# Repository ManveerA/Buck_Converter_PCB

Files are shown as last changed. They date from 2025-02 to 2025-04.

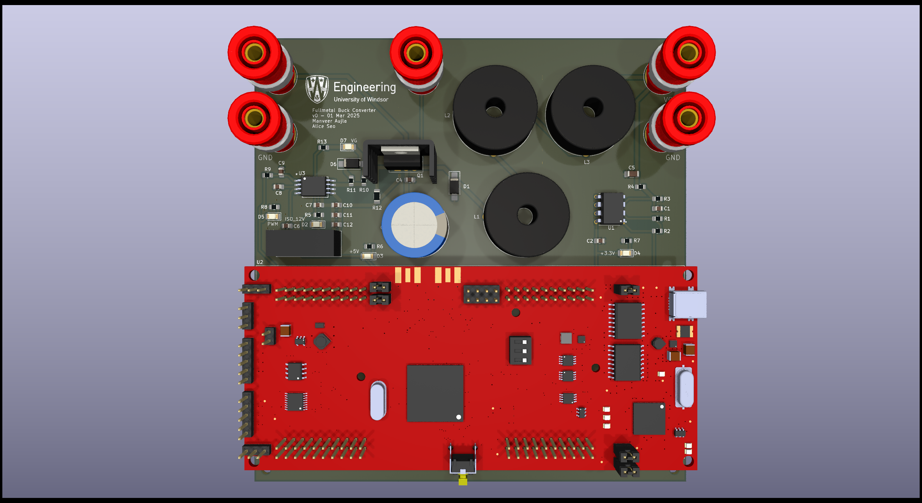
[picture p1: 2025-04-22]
3D_View.png

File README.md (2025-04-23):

Repository for Buck Converter PCB design project for ELEC-4450 Power Electronics.

See ELEC-4500 - Project Report.pdf for pictures of the board and see ELEC-4500 - Preliminary Design.pdf for the simulations and initial design.

Author: Manveer Aujla

Contact: aujla21@uwindsor.ca (school) | manveeraujla0226@gmail.com (personal) 

Last updated: 2025-04-23

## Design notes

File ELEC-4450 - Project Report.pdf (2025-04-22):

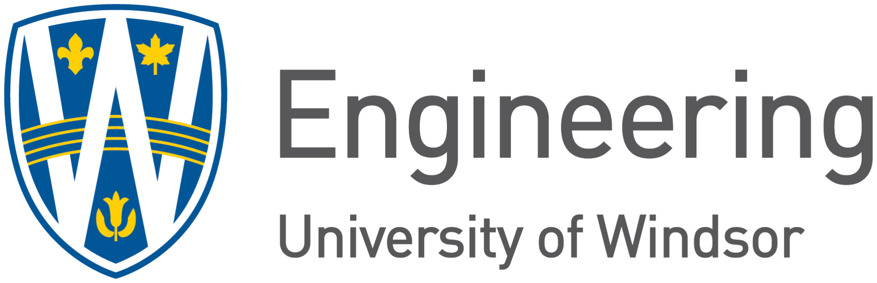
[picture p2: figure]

ELEC-4450: Power Electronics

Instructor: Dr. Caniggia Viana

## Switched-Mode Power Supply: Project Report

Manveer Aujla | 110072428
Alice Seo | 110072503

17 April 2025

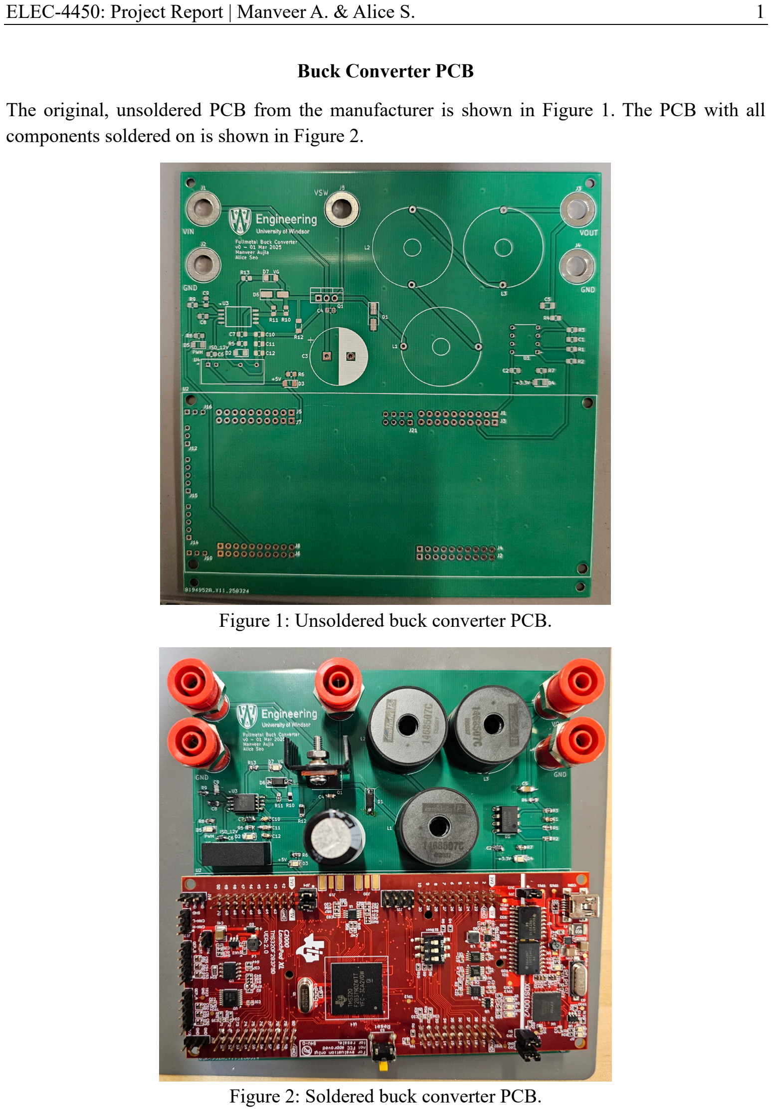
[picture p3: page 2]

ELEC-4450: Project Report | Manveer A. & Alice S. | 1

Buck Converter PCB
The original, unsoldered PCB from the manufacturer is shown in Figure 1. The PCB with all components soldered on is shown in Figure 2.

Figure 1: Unsoldered buck converter PCB.

Figure 2: Soldered buck converter PCB.

The converter connected to a laptop and the Festo machine, showing the appropriate LEDs lit, is shown in Figure 3.

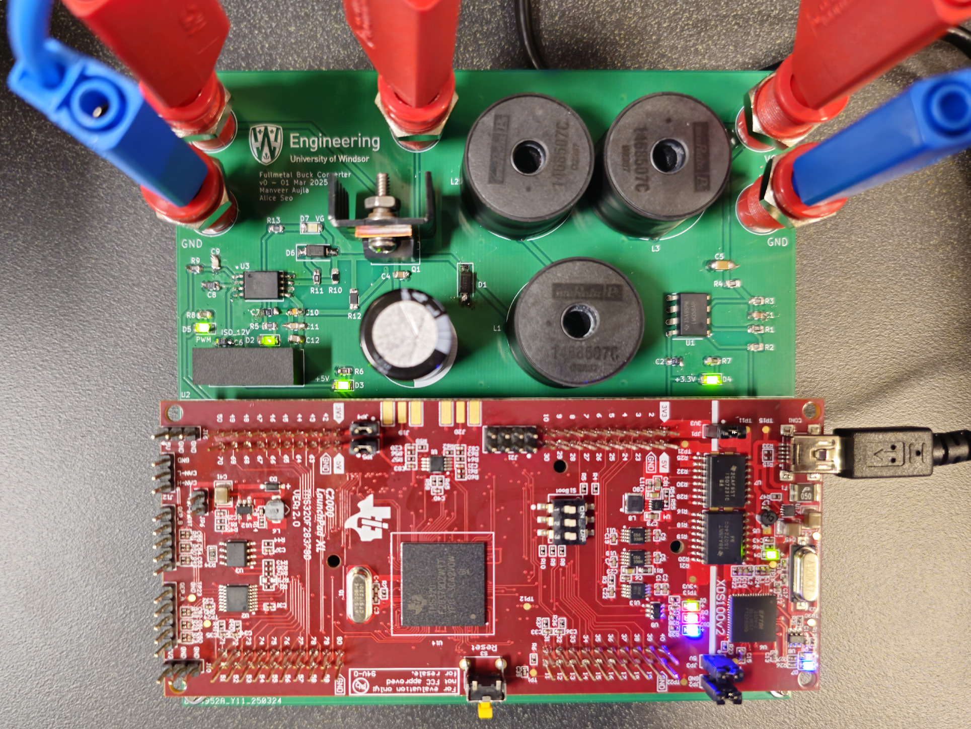
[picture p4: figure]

Figure 3: Converter connected to the laptop and Festo machine.

Design Changes
Since the Preliminary Design, only a few changes were made to the PCB design:
- Trace widths were increased to a minimum of 0.5 mm
- Surface-mounted LM358 op amp was replaced with a through-hole variant
- Mounting holes were added to the PCB layout
- GA-recommended MCU headers and standoffs were added to the BOM
Changes to the buck converter PCB that were made when debugging and testing are discussed thoroughly in the subsequent sections.

PCB Bring Up: Assembly
In the Preliminary Design, we formulated a PCB bring-up plan. This section describes the assembly and soldering process.
Out-of-Box Visual Inspection
All components ordered from Digikey were accounted for and the PCB from JLCPCB had no visual issues.
Build & Solder the Board
We have relatively little soldering experience, so soldering all of the components onto the board, particularly the surface-mounted gate driver IC, was a challenging but rewarding learning experience. We made some mistakes, such as soldering the Schottky diode in the wrong direction. However, we were able to remedy all mistakes without issue. With each component we soldered onto the board, we used a multimeter to check the continuity between adjacent components/pads to ensure that it matched the layout on KiCad.
Post-Solder Inspection
We made sure that all components were secured to the board as expected, mechanically and electrically. Using a multimeter, we performed a final sanity check on the board to ensure all connections were as expected.

PCB Bring Up: Testing & Debugging This section describes the testing and debugging process of our PCB.
IC Power and Sanity Test

The MCU was supplied with VVCC = 5 V from the Micro-USB connection to a laptop. We noted

that the +5V and +3.3V LEDs were on as expected. The ISO_12 LED, although on, was dimmer than the other LEDs. We had chosen resistors in series with each LED to provide roughly 10 mA of current for each specific voltage; since the LED was dim, it meant the output voltage from the isolated power supply was less than expected. The isolated power supply should take a 5 V input from the MCU and boost it to 12 V references to its isolated ground so that the gate driver can route it to bias the high-side switched MOSFET. We measured the output of the isolated power supply VVISO12 = 3.5 V (measuring ISO_12 with respect to ISO_GND). Apparently, the isolated

power supply was not doing its job.

We measured the resistance between ISO_12 to ISO_GND to be about RRISO-out = 3 kΩ, meaning

there was not a massive load (e.g., a DC short) demanding tons of current at the output side of the power supply. After investigation, our theory was that the isolated power supply IC must be defective. To fix this, we borrowed an IC from another group and desoldered the old, seemingly dysfunctional, IC. However, after desoldering the 4-pin IC (using three pairs of hands), solder remained on the through holes. It was too difficult to solder on the new IC because we would need to heat each pin simultaneously and push it into the PCB. So, we engineered a solution: using some jumper wires, electrical tape, and alligator clips, we attached the new isolated power supply to the board. To our dismay, repeating the IC power test showed ISO_12 was still measuring about 3.5
V. Thus, our hypothesis about the IC being broken was likely incorrect.
Next, we removed the isolated power supply from the PCB and applied an external 9-V battery at the ISO_12 and ISO_GND terminals of the PCB. To our surprise, this still did not work, and the voltage somehow became limited to 3.5 V or so. Naively, we put another battery in series and tried again—causing the board to smoke. We measured RRISO-out = 20 Ω which indicated that one of the VVDD capacitors had burned. Checking our BOM, the tantalum capacitor C10 has a voltage rating of 16 V. After removing C10, we checked the resistance RRISO-out once more and it returned to 3 kΩ.

Therefore, we correctly identified that C10 was burned and consequently internally shorted. With C10 removed, the isolated power supply now outputted 12 V. We later learned from the datasheet that C10 has a polarity, and our theory is that we had connected C10 with the wrong polarity which caused the isolated power supply to be unable to provide 12 V.
Full Power Test
The MCU was programmed using Simulink via the C2000 Microcontroller Blockset (https://www.mathworks.com/products/ti-c2000-microcontroller.html) using the Formula SAE MATLAB license. The Simulink model to program the firmware is shown in Figure
4. The PID block contains the controller CC(ss) made in the Preliminary Design.

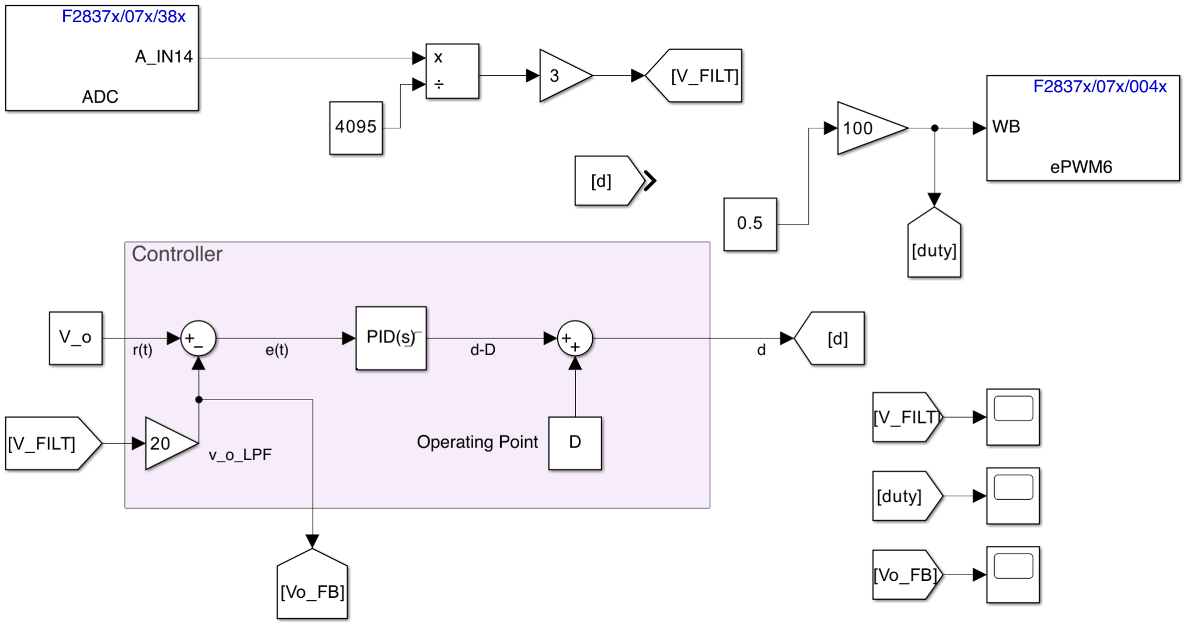
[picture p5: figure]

Figure 4: Simulink model using C2000 Microcontroller Blockset to build firmware. The test setup using the Festo machines is shown in Figure 5.

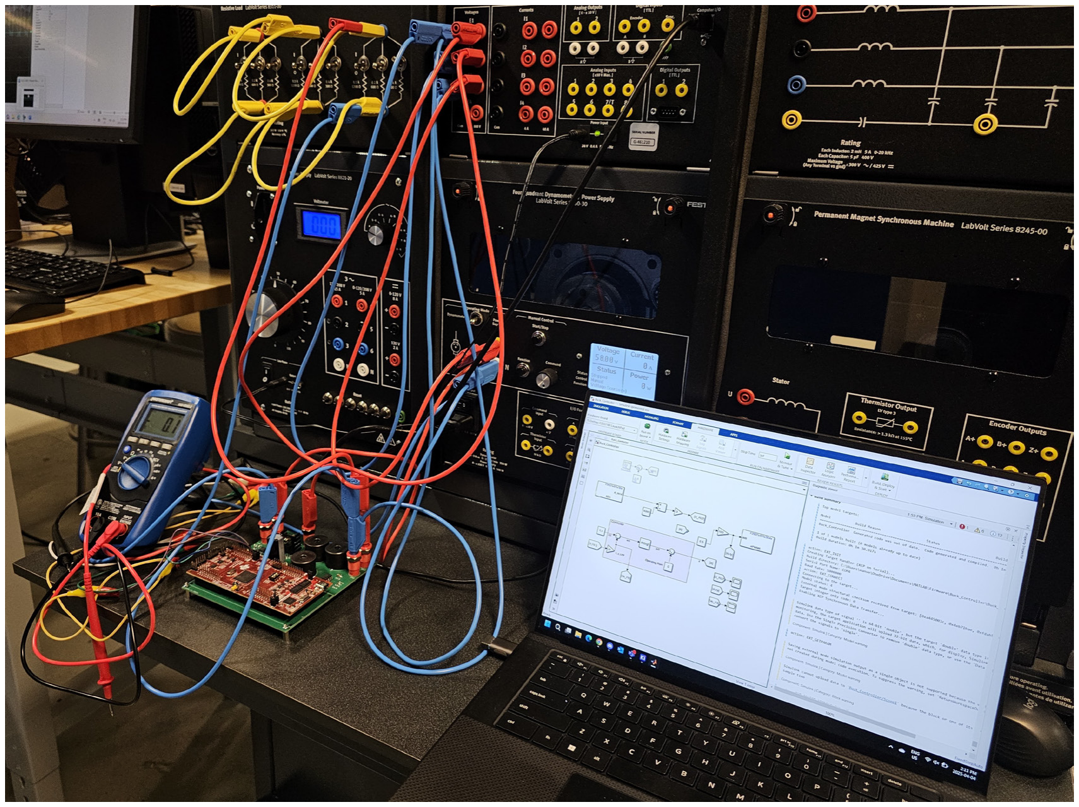
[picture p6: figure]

Figure 5: Test setup.

An input voltage of VVii = 10 V was applied to VIN from the Festo machine to the converter. The MCU was programmed for a voltage reference of VVoo

∗ = 5 V. Therefore, we would expect the duty cycle dd(tt) would adjust according to the controller such that the output voltage VVoo tracks the

reference. Unfortunately, this did not work; when the input voltage was switched on, the output voltage rose to nearly the input voltage before rapidly decaying to about 0–0.4 V and the duty cycle converged to a value of about 3.5%.
To debug, we needed to figure out whether this was a hardware or software problem. The MCU was programmed to manually set the duty cycle to 50%. In this attempt, with the input voltage of 10 V, the average output voltage went to 4.46 V, which roughly follows the conversion ratio for a buck converter. These results are shown in the next section. We then probed the hardware to compare to the ADC measurements and found that the ADC was measuring the correct voltage.

However, we noted that the LPF was not behaving as expected. Specifically, we noted that the VV+ and VV− terminals of the op amp measured a voltage difference of about 2 V or so. For an ideal op amp, VV+ = VV− and so we would expect this voltage difference to be nearly zero!

Our current hypothesis is the LPF stage hardware is compromised such that the ADC is getting a voltage reading larger than the actual normalized output voltage. In other words, since the ADC voltage determines the next iteration’s duty cycle, dd(tt) converging to 3.5% (when we expect it

should be at least greater than 50%) indicates that the controller is receiving information that we are at the reference voltage when dd(tt) = 3.5%, despite this being false. Problems notwithstanding,

we are happy that our PCB was able to, at the very least, operate as a buck converter for a given duty cycle. For true controlled buck operation, we will investigate and fix the LPF stage to achieve reference tracking for load transients.

Experimental Results
As mentioned in the previous section, our buck converter could only operate for a given duty cycle hardcoded in the firmware. That is, we were unable to use feedback control and track a reference due to hardware issues with the LPF stage. Waveforms for VVii = 5 V and dd(tt) = 100% are shown

in Figure 6.

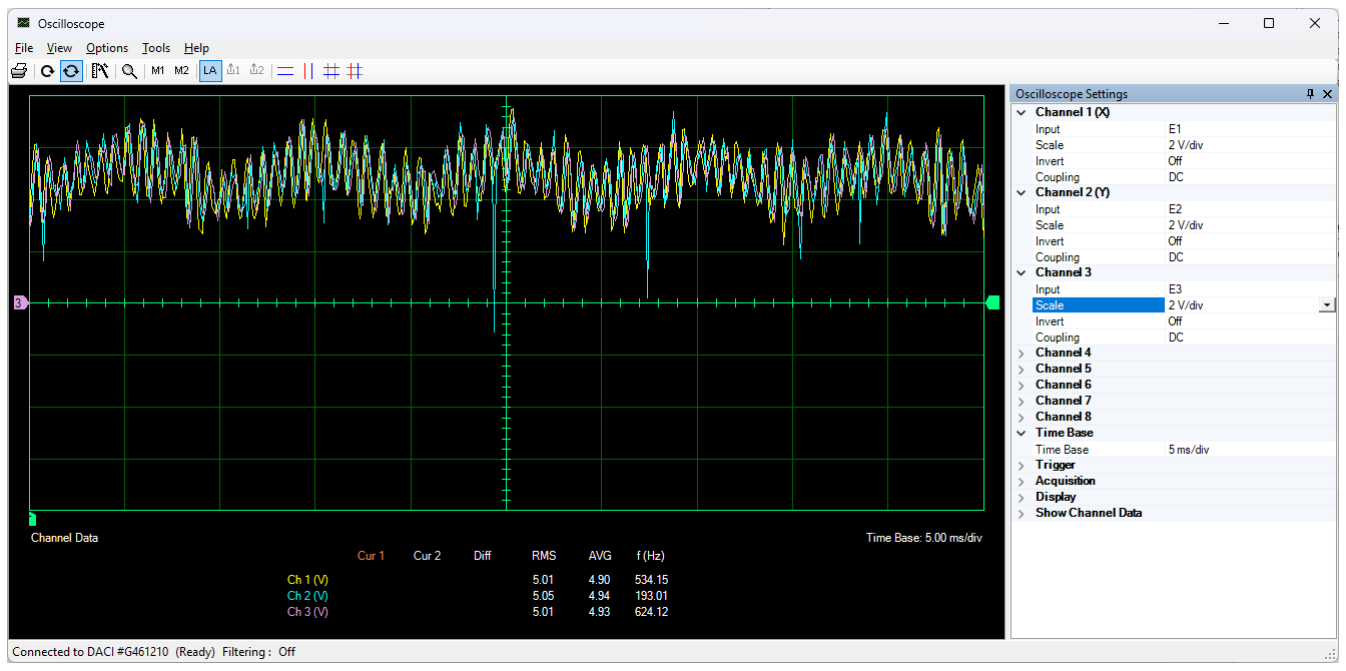
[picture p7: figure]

Figure 6: Waveforms of VVoo (Ch1), VVsw (Ch2), and VVii (Ch3) for VVii = 5 V and dd(tt) = 100%.

The input voltage essentially passes to the output, as expected with a duty cycle of 100%. That is,

VVii ≈ (100%)VVoo. Waveforms for VVii = 10 V and dd(tt) = 50% are shown in Figure 7.

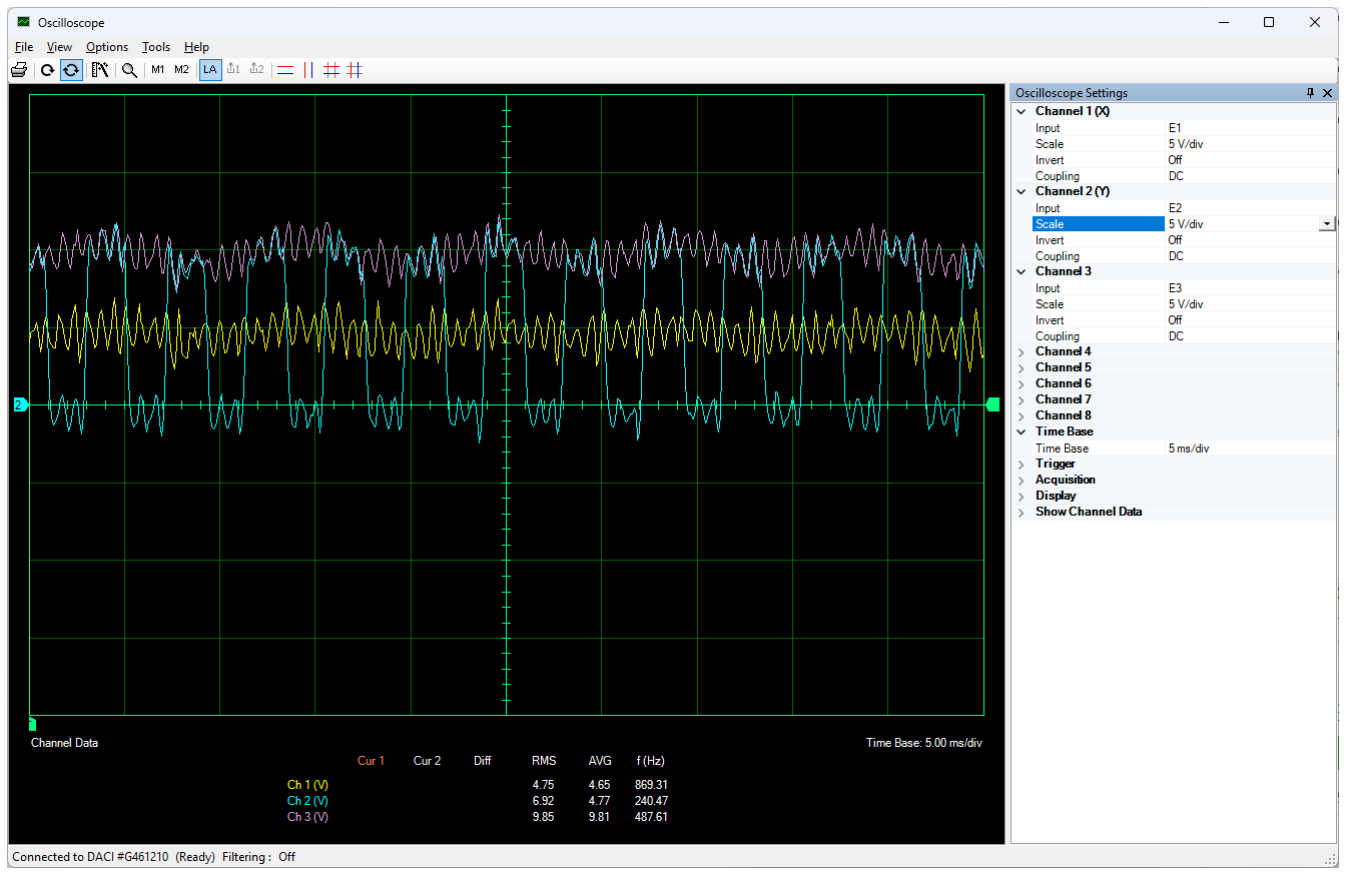
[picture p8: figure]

Figure 7: Waveforms of VVoo (Ch1), VVsw (Ch2), and VVii (Ch3) for VVii = 10 V and dd(tt) = 50%. For a duty cycle of 50%, an ideal buck would output VVoo = 50%VVii = 5 V. However, we have losses

that are unaccounted for; this is the purpose of the controller with feedback. Despite us not designing for the losses, the controller with feedback allows us to track references despite not using a robust model for the plant (i.e., the buck converter). Since we did not achieve feedback control, the best we could do was manually set a duty cycle. We can see that the buck converter is behaving as expected for its conversion ratio.

Individual Contribution
Manveer Aujla
My main contributions to the project include designing the PCB, designing and simulating the controller, selecting components based on the design constraints and making the BOM, soldering PCB components, debugging and reworking the PCB to make it functional as a buck converter, programming the firmware on the MCU, writing the bulk of the Preliminary Design, writing the ethical implications essay, and writing the final report.

Alice Seo
My contribution to the project includes checking over the PCB layout, components, and BOM, measuring the spacings between the components, soldering some PCB components and continuity testing, and contributing to writing the Preliminary Design and the ethical implications essay.

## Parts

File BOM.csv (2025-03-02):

Part Number | Reference | Value | Qty | Description | Datasheet | Footprint
CGA4J3X7R1H155K125AB | C1 | 1.5u | 1 | 1.5 ÂµF Â±10% 50V Ceramic Capacitor X7R 0805 (2012 Metric) | https://product.tdk.com/system/files/dam/doc/product/capacitor/ceramic/mlcc/catalog/mlcc_automotive_general_en.pdf | Capacitor_SMD:C_0805_2012Metric_Pad1.18x1.45mm_HandSolder
TMCP1D105MTRF | C2,C6,C7,C8 | 1u | 4 | 1 ÂµF Molded Tantalum Capacitors 20 V 0805 (2012 Metric) 11Ohm @ 100kHz | https://www.vishay.com/docs/40179/tmcp.pdf | Capacitor_SMD:C_0805_2012Metric_Pad1.18x1.45mm_HandSolder
100ZLH470MEFC16X31.5 | C3 | 470u | 1 | 470 ÂµF 100 V Aluminum Electrolytic Capacitors Radial, Can 10000 Hrs @ 105Â°C | https://www.rubycon.co.jp/wp-content/uploads/catalog-aluminum/ZLH.pdf | Capacitor_THT:CP_Radial_D18.0mm_P7.50mm
GRM21BC72A105KE01L | C4 | 1u | 1 | 1 ÂµF Â±10% 100V Ceramic Capacitor X7S 0805 (2012 Metric) | https://search.murata.co.jp/Ceramy/image/img/A01X/G101/ENG/GRM21BC72A105KE01-01.pdf | Capacitor_SMD:C_0805_2012Metric_Pad1.18x1.45mm_HandSolder
GRM31CC72A475KE11L | C5 | 4.7u | 1 | 4.7 ÂµF Â±10% 100V Ceramic Capacitor X7S 1206 (3216 Metric) | https://search.murata.co.jp/Ceramy/image/img/A01X/G101/ENG/GRM31CC72A475KE11-01A.pdf | Capacitor_SMD:C_1206_3216Metric_Pad1.33x1.80mm_HandSolder
C0805C330K5GACTU | C9 | 33p | 1 | 33 pF Â±10% 50V Ceramic Capacitor C0G, NP0 0805 (2012 Metric) | https://search.kemet.com/download/datasheet/C0805C330K5GAC7800 | Capacitor_SMD:C_0805_2012Metric_Pad1.18x1.45mm_HandSolder
F951C106MPAAQ2 | C10 | 10u | 1 | 10 ÂµF Conformal Coated Tantalum Capacitors 16 V 0805 (2012 Metric) 4Ohm | https://datasheets.kyocera-avx.com/F95.pdf | Capacitor_SMD:C_0805_2012Metric_Pad1.18x1.45mm_HandSolder
C0805C224K5RACTU | C11 | 220n | 1 | 0.22 ÂµF Â±10% 50V Ceramic Capacitor X7R 0805 (2012 Metric) | https://search.kemet.com/download/datasheet/C0805C224K5RAC7800 | Capacitor_SMD:C_0805_2012Metric_Pad1.18x1.45mm_HandSolder
GRM21BR61E106KA73L | C12 | 10u | 1 | 10 ÂµF Â±10% 25V Ceramic Capacitor X5R 0805 (2012 Metric) | https://search.murata.co.jp/Ceramy/image/img/A01X/G101/ENG/GRM21BR61E106KA73-01.pdf | Capacitor_SMD:C_0805_2012Metric_Pad1.18x1.45mm_HandSolder
SS310 | D1 | ---- | 1 | Diode 100 V 3A Surface Mount DO-214AC (SMA) | https://services.taiwansemi.com/storage/resources/datasheet/SS32%20SERIES_Q2412.pdf | Diode_SMD:D_SMA_Handsoldering
LTST-C150GKT | D2,D3,D4,D5,D7 | ---- | 5 | Green 569nm LED Indication - Discrete 2.1V | https://optoelectronics.liteon.com/upload/download/DS-22-98-0004/LTST-C150GKT.pdf | LED_SMD:LED_1206_3216Metric_Pad1.42x1.75mm_HandSolder
US2AA | D6 | ---- | 1 | 50V, 1.5A, General Purpose Rectifier Diode, SMA(DO-214AC) | https://www.onsemi.com/pdf/datasheet/us2aa-d.pdf | Diode_SMD:D_SMA_Handsoldering
BU-P72930-2 | J1,J2,J3,J4,J5 | ---- | 5 | Generic connector, single row, 01x01, script generated | https://www.muellerelectric.com/product_files/986/DS-BU-P72930-@.pdf | Connector:Banana_Jack_1Pin
1468507C | L1,L2,L3 | 6.8m | 3 | FIXED IND 6.8MH 700MA 2.3 OHM TH | https://search.murata.co.jp/Ceramy/image/img/P02A/kmp_1400.pdf | Inductor_THT:L_Radial_D24.4mm_P23.10mm_Murata_1400series
IRF540NPBF | Q1 | ---- | 1 | N-Channel 100 V 33A (Tc) 130W (Tc) Through Hole TO-220AB | https://www.infineon.com/dgdl/irf540npbf.pdf?fileId=5546d462533600a4015355e39f0d19a1 | Package_TO_SOT_THT:TO-220-3_Vertical
507302B00000G | Q1 Heatsink | ---- | 1 | Heatsink for MOSFET | https://info.boydcorp.com/hubfs/Thermal/Air-Cooling/Boyd-Board-Level-Heatsinks-Catalog.pdf | ----
4880G | Q1 Heatsink Mounting Kit | ---- | 1 | Mounting kit for heatsink for MOSFET | https://info.boydcorp.com/hubfs/Thermal/Air-Cooling/Boyd-Board-Level-Heatsinks-Catalog.pdf | ----
RC0805FR-0720KL | R1,R4 | 20k | 2 | 20 kOhms Â±1% 0.125W, 1/8W Chip Resistor 0805 (2012 Metric) Moisture Resistant Thick Film | https://www.yageo.com/upload/media/product/products/datasheet/rchip/PYu-RC_Group_51_RoHS_L_12.pdf | Resistor_SMD:R_0805_2012Metric_Pad1.20x1.40mm_HandSolder
RMCF0805FT1K00 | R2,R3,R5,R13 | 1k | 4 | 1 kOhms Â±1% 0.125W, 1/8W Chip Resistor 0805 (2012 Metric) Automotive AEC-Q200 Thick Film | https://www.seielect.com/catalog/sei-rmcf_rmcp.pdf | Resistor_SMD:R_0805_2012Metric_Pad1.20x1.40mm_HandSolder
RMCF0805JT300R | R6 | 300R | 1 | 300 Ohms Â±5% 0.125W, 1/8W Chip Resistor 0805 (2012 Metric) Automotive AEC-Q200 Thick Film | https://www.seielect.com/catalog/sei-rmcf_rmcp.pdf | Resistor_SMD:R_0805_2012Metric_Pad1.20x1.40mm_HandSolder
RMCF0805FT120R | R7,R8 | 120R | 2 | 120 Ohms Â±1% 0.125W, 1/8W Chip Resistor 0805 (2012 Metric) Automotive AEC-Q200 Thick Film | https://www.seielect.com/catalog/sei-rmcf_rmcp.pdf | Resistor_SMD:R_0805_2012Metric_Pad1.20x1.40mm_HandSolder
RC0805FR-0751RL | R9 | 51R | 1 | 51 Ohms Â±1% 0.125W, 1/8W Chip Resistor 0805 (2012 Metric) Moisture Resistant Thick Film | https://www.yageo.com/upload/media/product/products/datasheet/rchip/PYu-RC_Group_51_RoHS_L_12.pdf | Resistor_SMD:R_0805_2012Metric_Pad1.20x1.40mm_HandSolder
RCS08056R80FKEA | R10 | 6.8R | 1 | 6.8 Ohms Â±1% 0.5W, 1/2W Chip Resistor 0805 (2012 Metric) Automotive AEC-Q200, Pulse Withstanding Thick Film | https://www.vishay.com/docs/20065/rcse3.pdf | Resistor_SMD:R_0805_2012Metric_Pad1.20x1.40mm_HandSolder
ERJ-P06J120V | R11 | 12R | 1 | 12 Ohms Â±5% 0.5W, 1/2W Chip Resistor 0805 (2012 Metric) Automotive AEC-Q200, Pulse Withstanding Thick Film | https://industrial.panasonic.com/cdbs/www-data/pdf/RDO0000/AOA0000C331.pdf | Resistor_SMD:R_0805_2012Metric_Pad1.20x1.40mm_HandSolder
RCP1206W50R0GEB | R12 | 50R | 1 | 50 Ohms Â±2% 2.4W Chip Resistor 1206 (3216 Metric) Moisture Resistant Thick Film | https://www.vishay.com/docs/31098/rcp.pdf | Resistor_SMD:R_1206_3216Metric_Pad1.30x1.75mm_HandSolder
LM358AP | U1 | ---- | 1 | General Purpose Amplifier 2 Circuit 8-PDIP | https://www.ti.com/general/docs/suppproductinfo.tsp?distId=10 | LM358AP:DIP794W45P254L959H508Q8
LAUNCHXL-F28379D | U2 | ---- | 1 | MCU Launchpad | https://www.ti.com/lit/pdf/sprui77 | LAUNCHXL_F28379D:MOD_LAUNCHXL-F28379D
61202021621 | U2 Connection Header | ---- | 4 | Connector Header Through Hole 20 position 0.100" (2.54mm) | https://www.we-online.com/components/products/datasheet/61202021621.pdf | ----
971100154 | PCB Standoffs | ---- | 4 | Hex Standoff Threaded M2.5 Brass 0.394" (10.00mm) Silver | https://www.we-online.com/components/products/datasheet/971100154.pdf | ----
4707 | Standoff nuts | ---- | 4 | M2.5x0.45 Hex Nut 0.197" (5.00mm) Steel | https://www.keyelco.com/userAssets/file/M65p135.pdf | ----
UCC5304DWVR | U3 | ---- | 1 | 4A, 6A Gate Driver Capacitive Coupling 5000Vrms 1 Channel 8-SOIC | https://www.ti.com/lit/gpn/ucc5304 | UCC5304DWVR:SOIC8_DWV_TEX
TMV 0512SHI | U4 | ---- | 1 | Isolated Module DC DC Converter 1 Output 12V 84mA 4.5V - 5.5V Input | https://www.tracopower.com/products/tmv-hi.pdf | TMV_0512SHI:TMV-HI_SINGLE_TRP

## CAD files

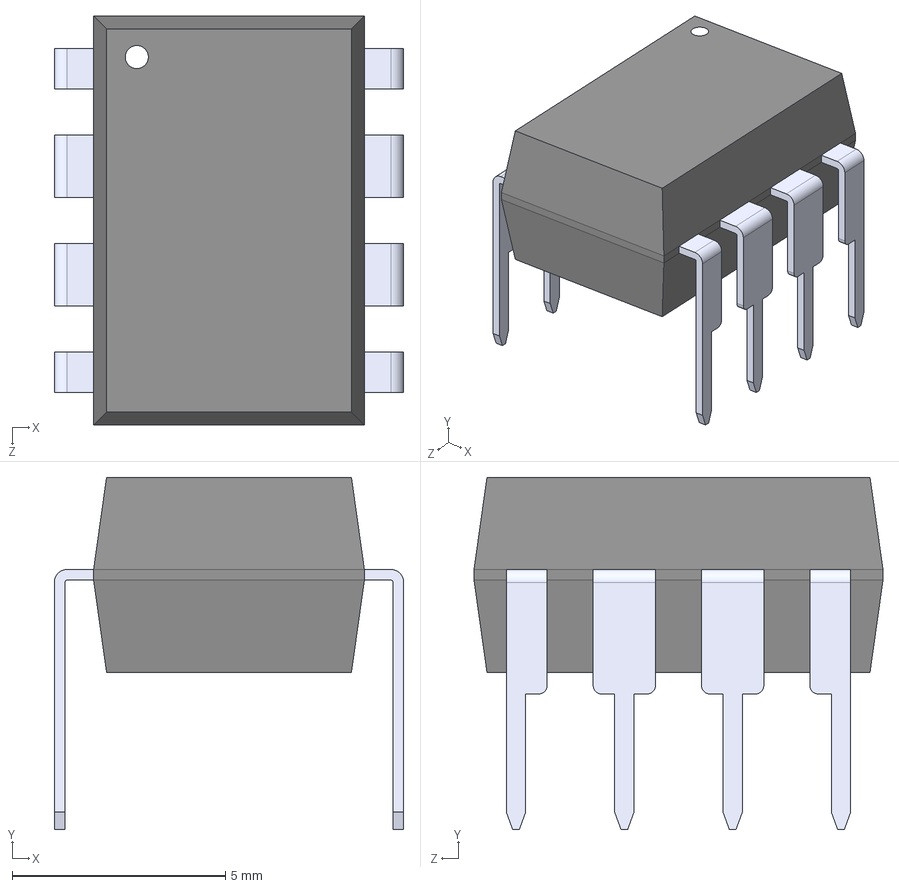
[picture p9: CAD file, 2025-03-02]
LM358AP/LM358AP.step
8.19 x 8.26 x 9.59 mm

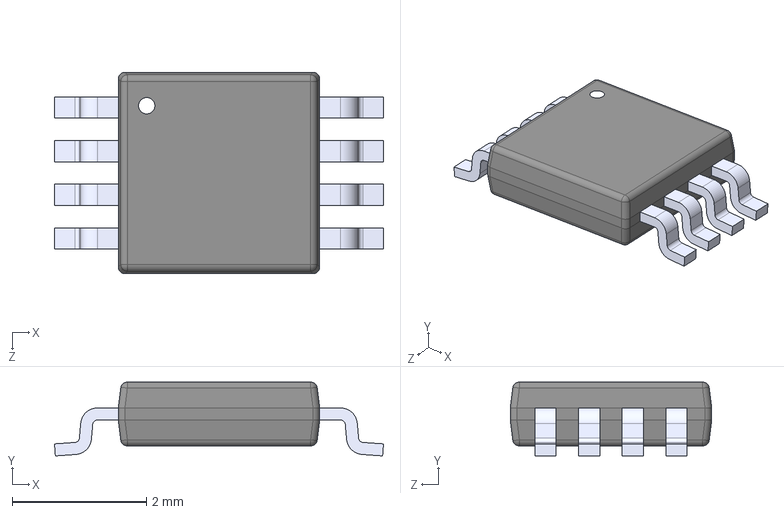
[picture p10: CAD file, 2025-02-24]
Misc/LM358DGKR.step
4.90 x 1.10 x 3.00 mm

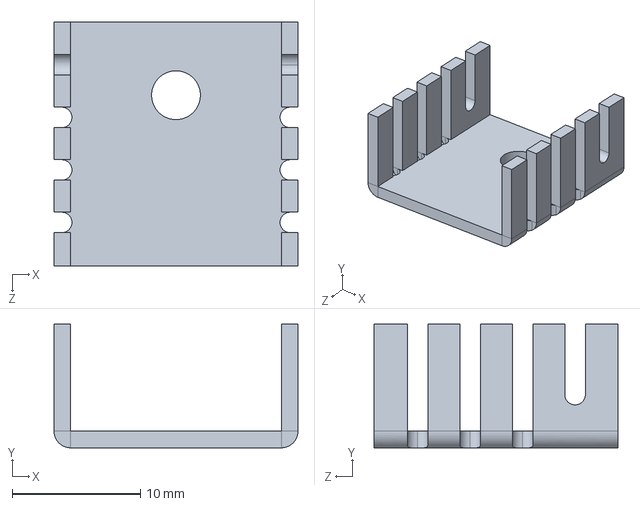
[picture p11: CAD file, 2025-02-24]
507302B00000G/507302B00000G.step
19.1 x 9.65 x 19.1 mm

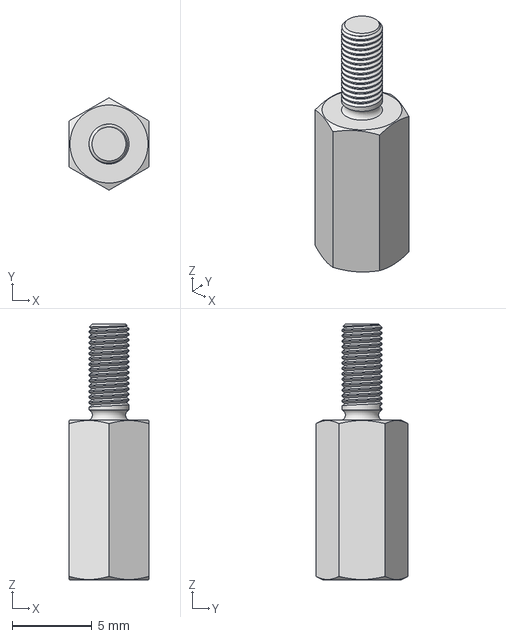
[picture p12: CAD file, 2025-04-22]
Misc/971100154.stp
5.00 x 5.77 x 16.0 mm

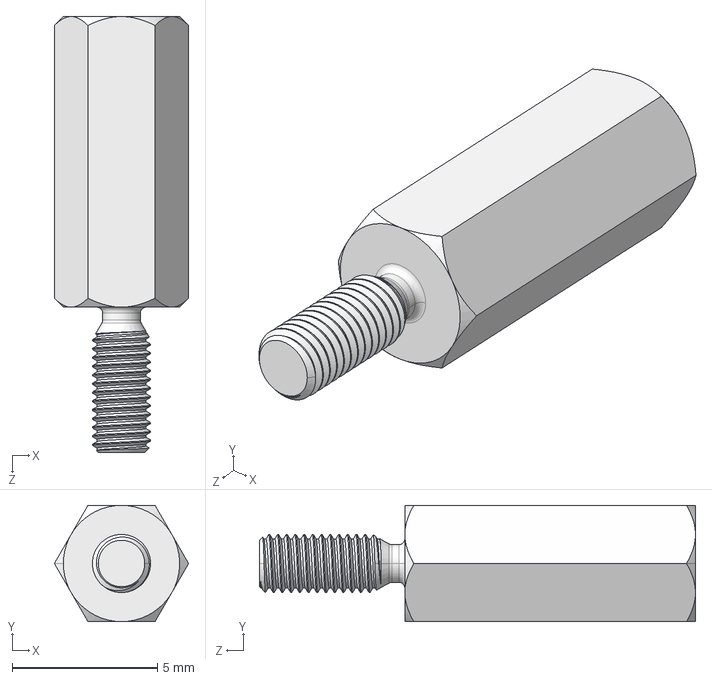
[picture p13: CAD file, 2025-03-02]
Misc/971100244.stp
4.62 x 4.00 x 15.0 mm

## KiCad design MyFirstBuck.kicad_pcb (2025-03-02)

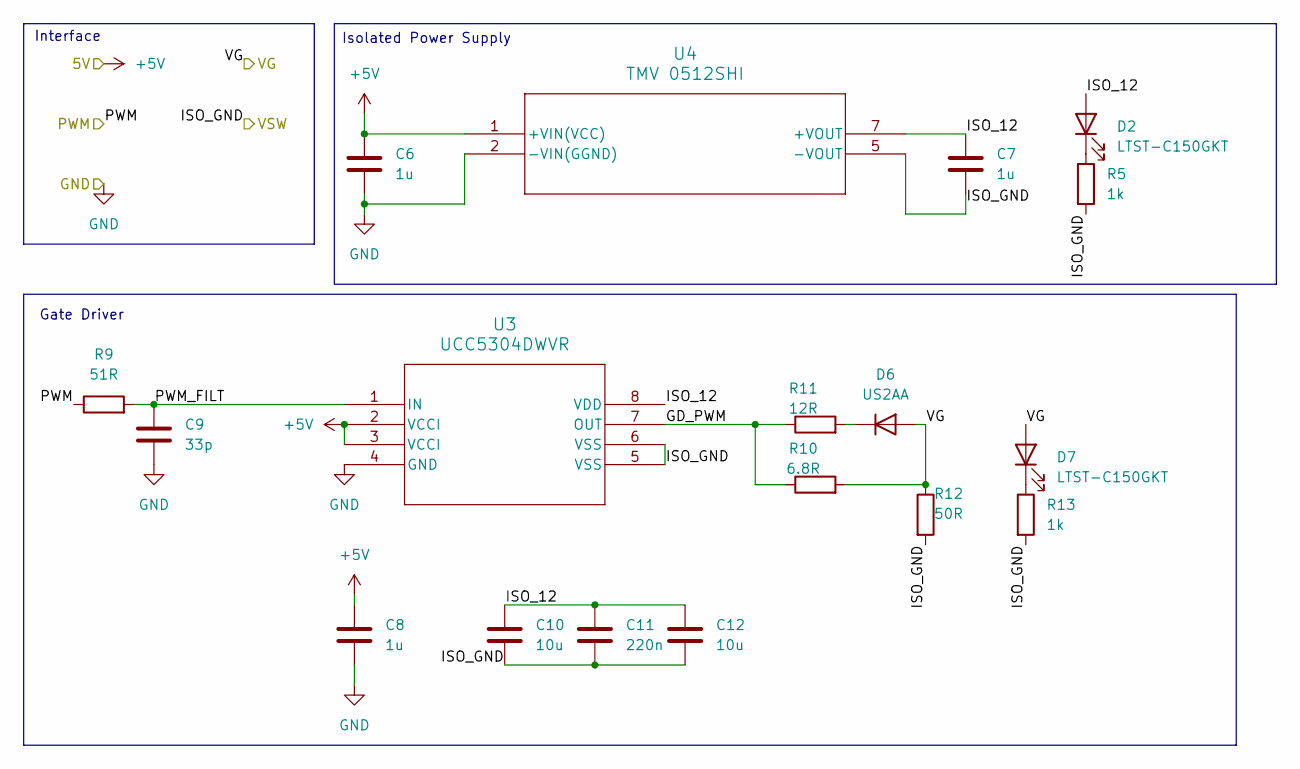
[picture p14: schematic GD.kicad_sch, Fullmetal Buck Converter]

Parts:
C6, C7, C8: 1u; C_0805_2012Metric_Pad1.18x1.45mm_HandSolder; Part Number TMCP1D105MTRF
C9: 33p; C_0805_2012Metric_Pad1.18x1.45mm_HandSolder; Part Number C0805C330K5GACTU
C10: 10u; C_0805_2012Metric_Pad1.18x1.45mm_HandSolder; Part Number F951C106MPAAQ2
C11: 220n; C_0805_2012Metric_Pad1.18x1.45mm_HandSolder; Part Number C0805C224K5RACTU
C12: 10u; C_0805_2012Metric_Pad1.18x1.45mm_HandSolder; Part Number GRM21BR61E106KA73L
D2, D7: LTST-C150GKT; LED_1206_3216Metric_Pad1.42x1.75mm_HandSolder; Part Number LTST-C150GKT
D6: US2AA; D_SMA_Handsoldering; Part Number US2AA
R5, R13: 1k; R_0805_2012Metric_Pad1.20x1.40mm_HandSolder; Part Number RMCF0805FT1K00
R9: 51R; R_0805_2012Metric_Pad1.20x1.40mm_HandSolder; Part Number RC0805FR-0751RL
R10: 6.8R; R_0805_2012Metric_Pad1.20x1.40mm_HandSolder; Part Number RCS08056R80FKEA
R11: 12R; R_0805_2012Metric_Pad1.20x1.40mm_HandSolder; Part Number ERJ-P06J120V
R12: 50R; R_1206_3216Metric_Pad1.30x1.75mm_HandSolder; Part Number RCP1206W50R0GEB
U3: UCC5304DWVR; SOIC8_DWV_TEX; Part Number UCC5304DWVR
U4: TMV 0512SHI; TMV-HI_SINGLE_TRP; Part Number TMV 0512SHI

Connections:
+5V: C6.1, C8.1, U3.2 (VCCI), U3.3 (VCCI), U4.1 (+VIN(VCC)); also elsewhere on the board
/GD/GD_PWM: R10.1, R11.1, U3.7 (OUT)
/GD/ISO_12: C7.1, C10.1, C11.1, C12.1, D2.2 (A), U3.8 (VDD), U4.7 (+VOUT)
/GD/PWM_FILT: C9.1, R9.2, U3.1 (IN)
/PWM: R9.1; also elsewhere on the board
/VG: D6.2 (A), D7.2 (A), R10.2, R12.1; also elsewhere on the board
/VSW: C7.2, C10.2, C11.2, C12.2, R5.2, R12.2, R13.2, U3.5 (VSS), U3.6 (VSS), U4.5 (-VOUT); also elsewhere on the board
GND: C6.2, C8.2, C9.2, U3.4 (GND), U4.2 (-VIN(GGND)); also elsewhere on the board
unnamed: D2.1 (K), R5.1
unnamed: D6.1 (K), R11.2
unnamed: D7.1 (K), R13.1

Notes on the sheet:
Interface
Isolated Power Supply
Gate Driver

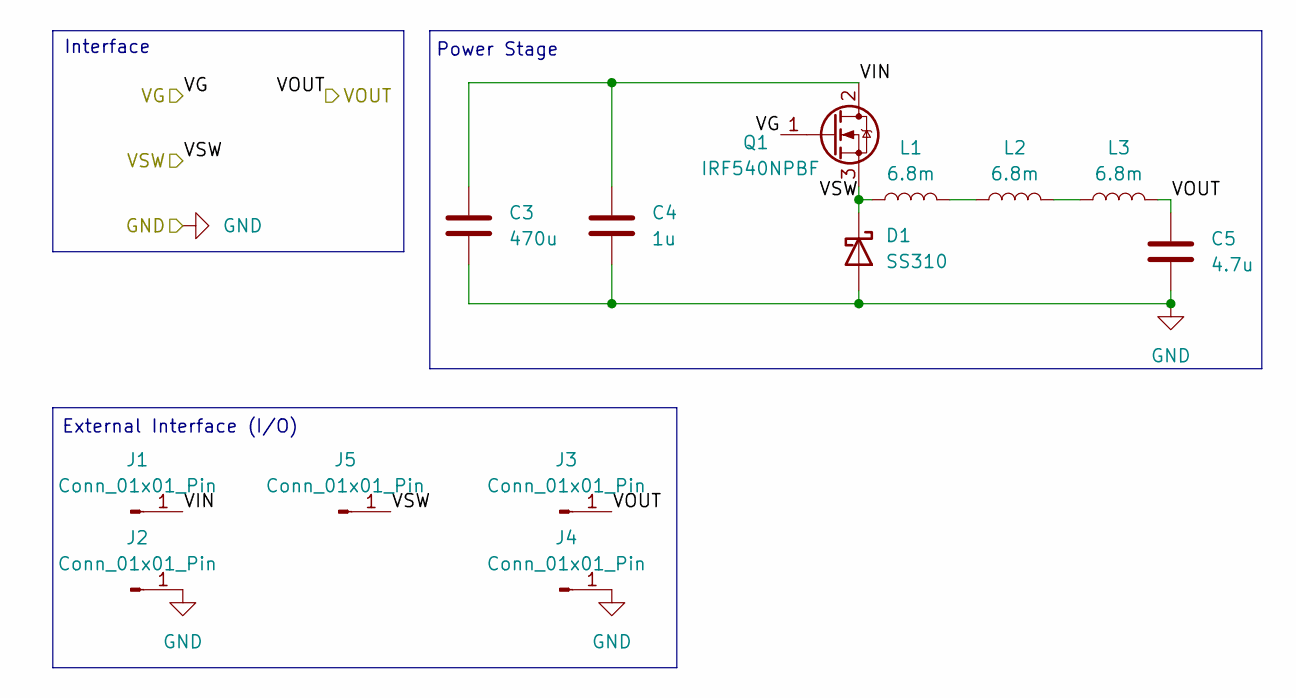
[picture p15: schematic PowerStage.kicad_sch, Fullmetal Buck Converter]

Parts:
C3: 470u; CP_Radial_D18.0mm_P7.50mm; Part Number 100ZLH470MEFC16X31.5
C4: 1u; C_0805_2012Metric_Pad1.18x1.45mm_HandSolder; Part Number GRM21BC72A105KE01L
C5: 4.7u; C_1206_3216Metric_Pad1.33x1.80mm_HandSolder; Part Number GRM31CC72A475KE11L
D1: SS310; D_SMA_Handsoldering; Part Number SS310
J1, J2, J3, J4, J5: Conn_01x01_Pin; Banana_Jack_1Pin; Part Number BU-P72930-2
L1, L2, L3: 6.8m; L_Radial_D24.4mm_P23.10mm_Murata_1400series; Part Number 1468507C
Q1: IRF540NPBF; TO-220-3_Vertical; Part Number IRF540NPBF

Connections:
/PowerStage/VIN: C3.1, C4.1, J1.1, Q1.2 (D)
/VG: Q1.1 (G); also elsewhere on the board
/VOUT: C5.1, J3.1, L3.2; also elsewhere on the board
/VSW: D1.1 (K), J5.1, L1.1, Q1.3 (S); also elsewhere on the board
GND: C3.2, C4.2, C5.2, D1.2 (A), J2.1, J4.1; also elsewhere on the board
unnamed: L1.2, L2.1
unnamed: L2.2, L3.1

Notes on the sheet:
External Interface (I/O)
Interface
Power Stage

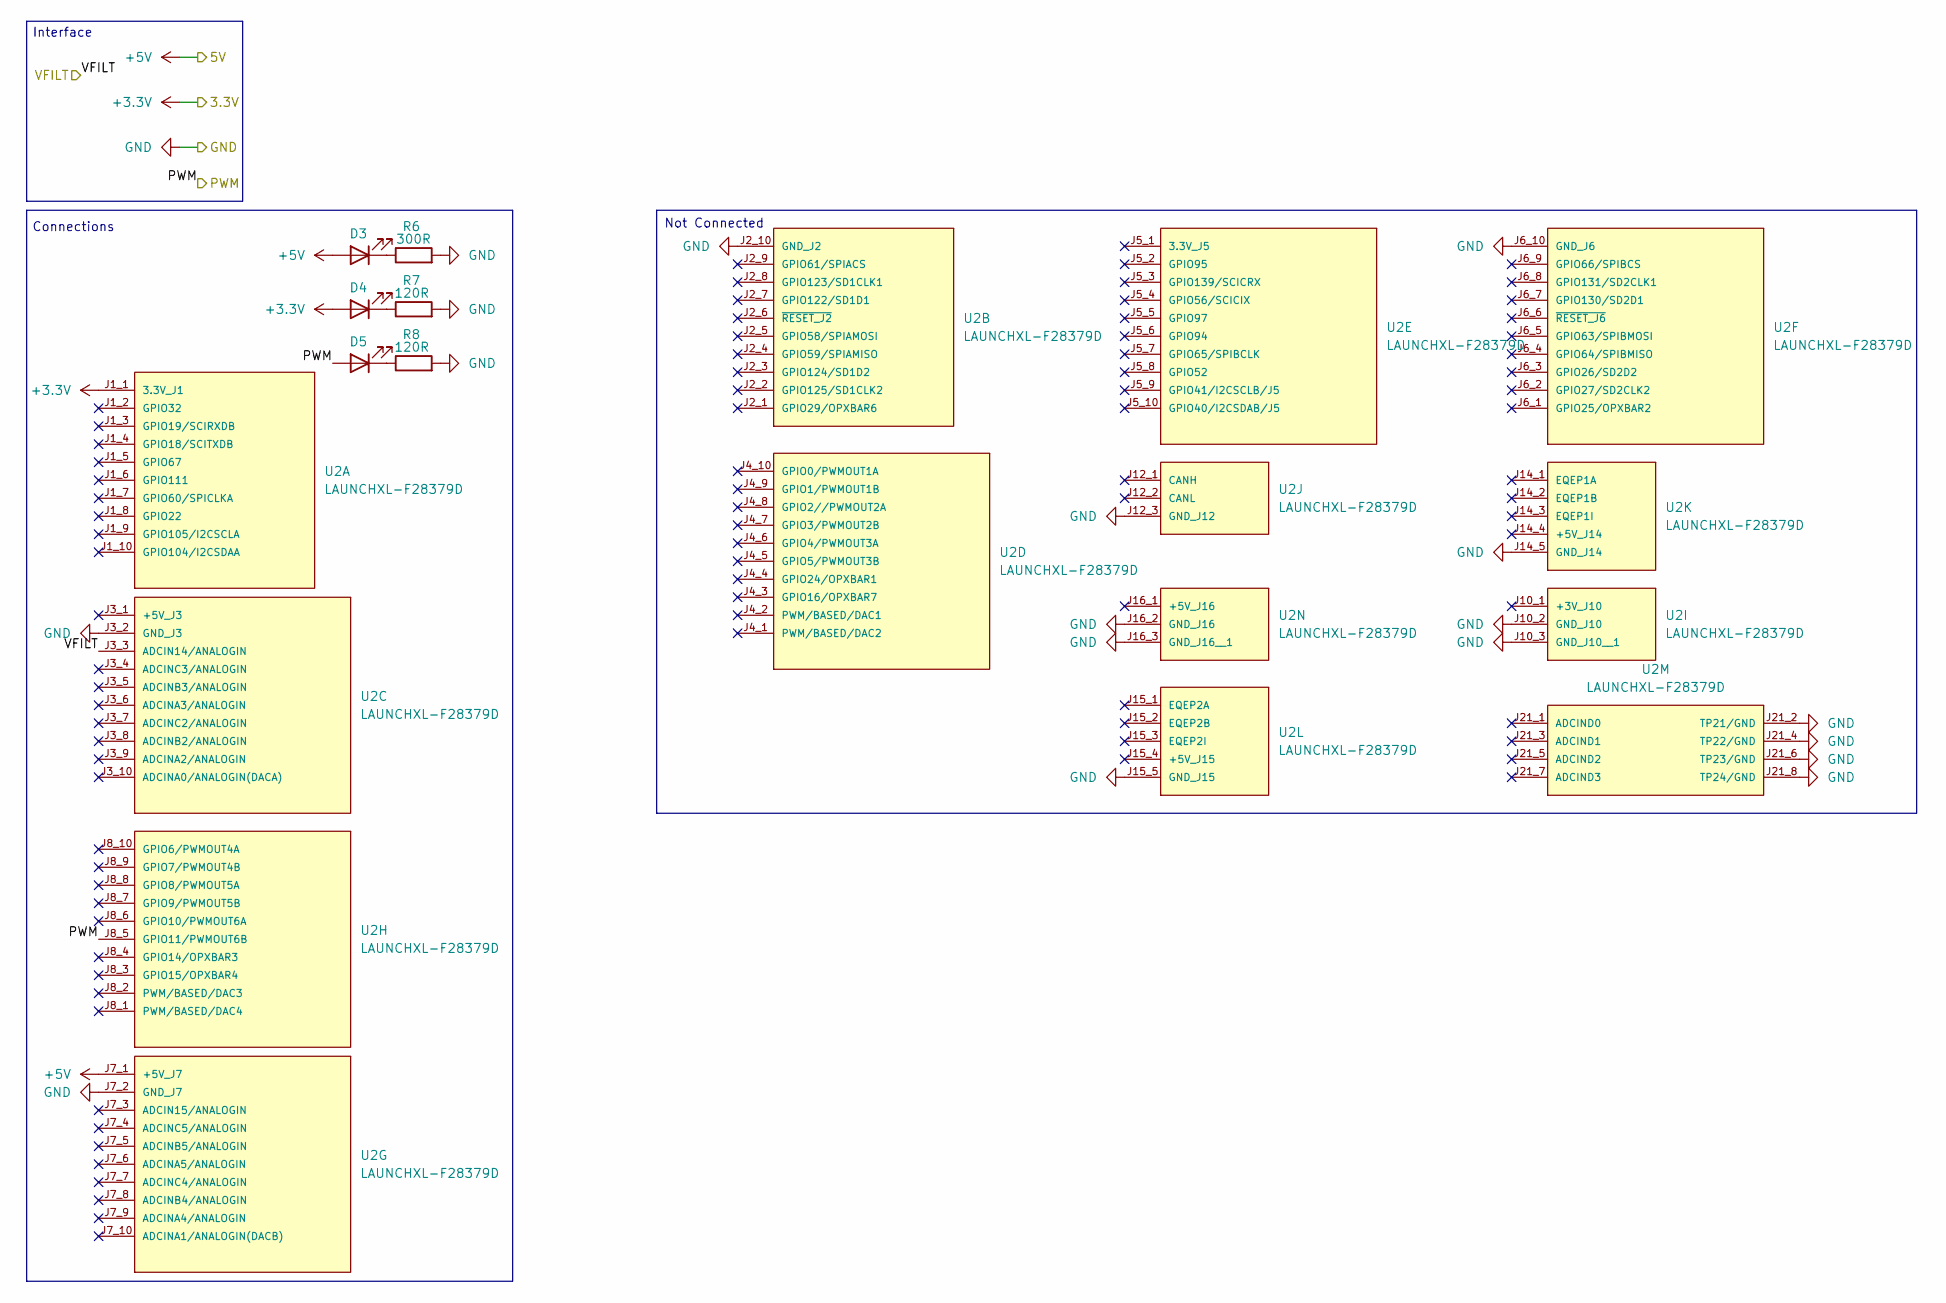
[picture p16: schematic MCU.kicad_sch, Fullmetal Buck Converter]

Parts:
D3, D4, D5: LTST-C150GKT; LED_1206_3216Metric_Pad1.42x1.75mm_HandSolder; Part Number LTST-C150GKT
R6: 300R; R_0805_2012Metric_Pad1.20x1.40mm_HandSolder; Part Number RMCF0805JT300R
R7, R8: 120R; R_0805_2012Metric_Pad1.20x1.40mm_HandSolder; Part Number RMCF0805FT120R
U2: LAUNCHXL-F28379D; MOD_LAUNCHXL-F28379D; PARTREV 2.0

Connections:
+3.3V: D4.2 (A), U2.J1_1 (3.3V_J1); also elsewhere on the board
+5V: D3.2 (A), U2.J7_1 (+5V_J7); also elsewhere on the board
/PWM: D5.2 (A), U2.J8_5 (GPIO11/PWMOUT6B); also elsewhere on the board
/VFILT: U2.J3_3 (ADCIN14/ANALOGIN); also elsewhere on the board
GND: R6.2, R7.2, R8.2, U2.J2_10 (GND_J2), U2.J3_2 (GND_J3), U2.J6_10 (GND_J6), U2.J7_2 (GND_J7), U2.J10_2 (GND_J10), U2.J10_3 (GND_J10__1), U2.J12_3 (GND_J12), U2.J14_5 (GND_J14), U2.J15_5 (GND_J15), U2.J16_2 (GND_J16), U2.J16_3 (GND_J16__1), U2.J21_2 (TP21/GND), U2.J21_4 (TP22/GND), U2.J21_6 (TP23/GND), U2.J21_8 (TP24/GND); also elsewhere on the board
unnamed: D3.1 (K), R6.1
unnamed: D4.1 (K), R7.1
unnamed: D5.1 (K), R8.1

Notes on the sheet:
Interface
Not Connected
Connections

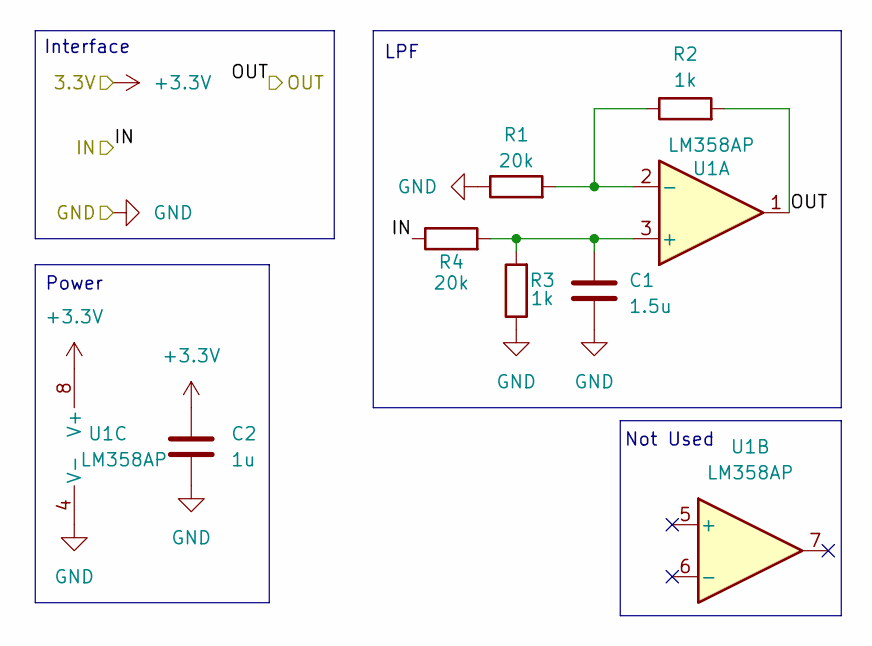
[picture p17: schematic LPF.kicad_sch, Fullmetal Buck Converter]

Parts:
C1: 1.5u; C_0805_2012Metric_Pad1.18x1.45mm_HandSolder; Part Number CGA4J3X7R1H155K125AB
C2: 1u; C_0805_2012Metric_Pad1.18x1.45mm_HandSolder; Part Number TMCP1D105MTRF
R1, R4: 20k; R_0805_2012Metric_Pad1.20x1.40mm_HandSolder; Part Number RC0805FR-0720KL
R2, R3: 1k; R_0805_2012Metric_Pad1.20x1.40mm_HandSolder; Part Number RMCF0805FT1K00
U1: LM358AP; DIP794W45P254L959H508Q8; Part Number LM358AP

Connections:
+3.3V: C2.1, U1.8 (V+); also elsewhere on the board
/VFILT: R2.2, U1.1; also elsewhere on the board
/VOUT: R4.1; also elsewhere on the board
GND: C1.2, C2.2, R1.1, R3.1, U1.4 (V-); also elsewhere on the board
unnamed: C1.1, R3.2, R4.2, U1.3 (+)
unnamed: R1.2, R2.1, U1.2 (-)

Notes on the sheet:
Power
Interface
Not Used
LPF

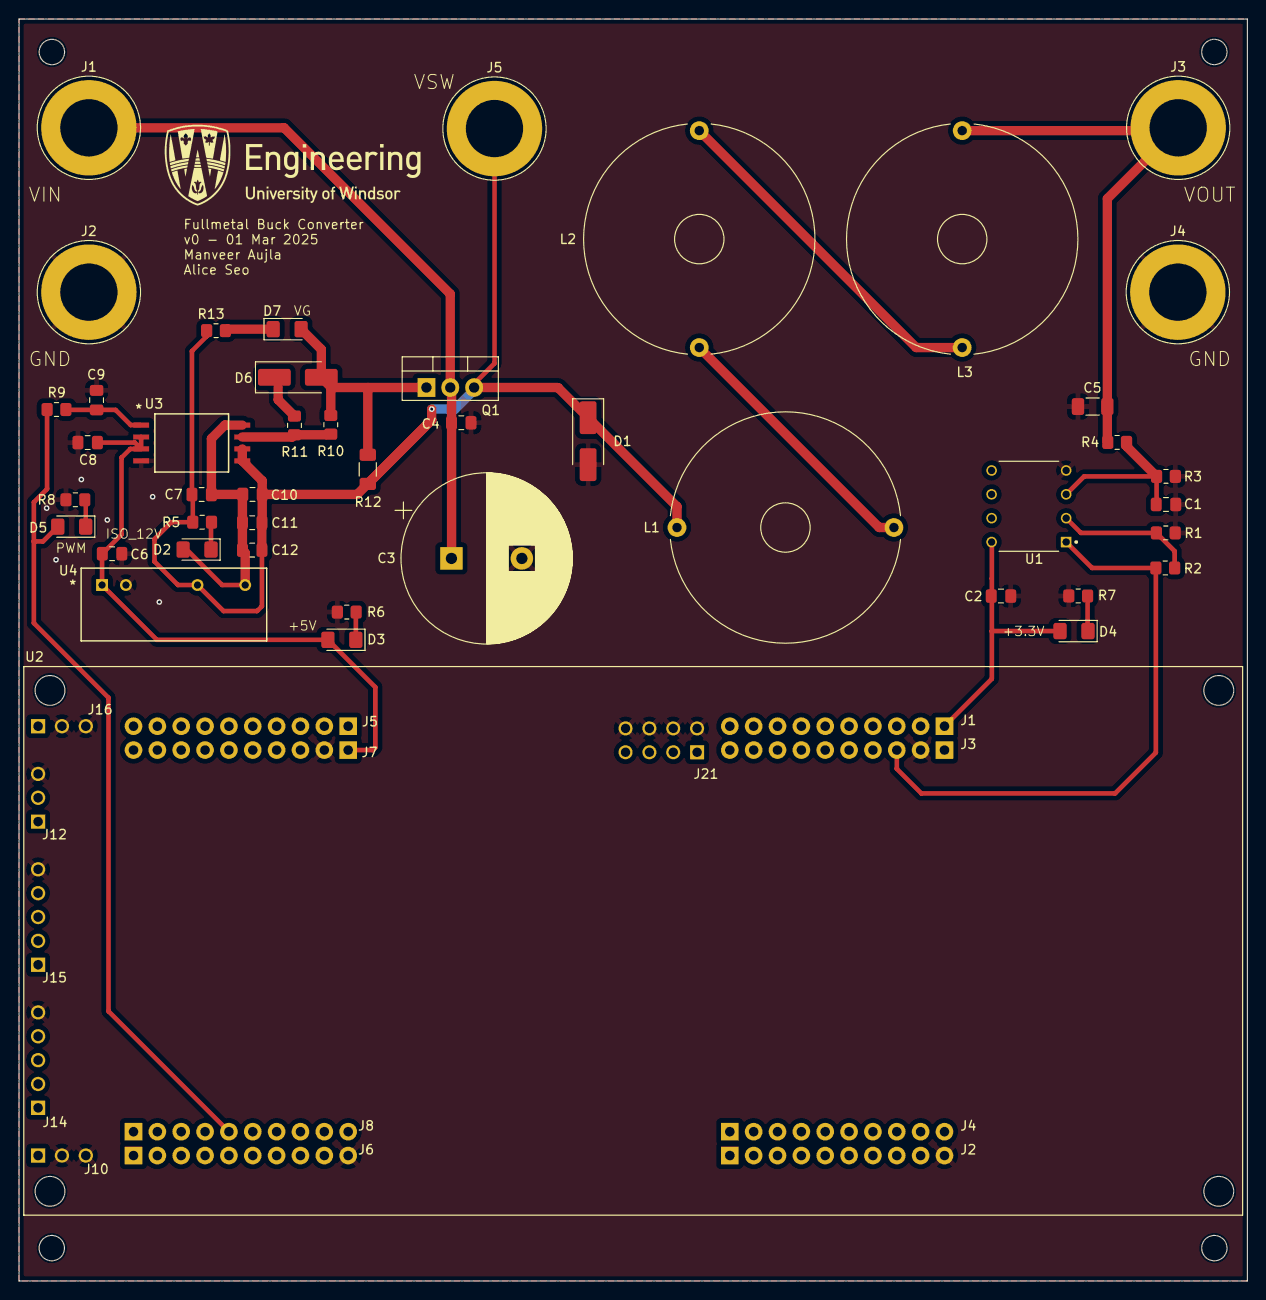
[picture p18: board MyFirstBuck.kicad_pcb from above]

Board: 2 copper layers, 130.8 x 134.4 mm, 45 parts (0 on the bottom side), 22 nets.
